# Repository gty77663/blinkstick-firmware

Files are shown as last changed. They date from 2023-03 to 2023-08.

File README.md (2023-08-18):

# BlinkStick Firmware

BlinkStick is a DIY open source USB RGB LED Controller. Original idea is to create a little & handy RGB stick, and make its code and protocol opensource, so everybody can enjoy playing with RGB LEDs using the programming launguage or application of your choise. It's small, the biggest model is the size of a credit card and supports both popular types of RGB LEDs - generic 12V ones and addressable WS2812. 

You can find more details about it here:

http://www.blinkstick.com

This branch contains the firmware required for the BlinkStick(original one), based around ATtiny45/85 chip.

- [BlinkStick Firmware](#blinkstick-firmware)
  - [BlinkStick types](#blinkstick-types)
  - [Serial number](#serial-number)
  - [BlinkStick communication protocol](#blinkstick-communication-protocol)
  - [EEPROM memory map](#eeprom-memory-map)
  - [How to build the firmware](#how-to-build-the-firmware)
    - [Windows](#windows)
    - [Linux](#linux)
    - [Mac-OS](#mac-os)
    - [Compiling](#compiling)
  - [TODO](#todo)
  - [License](#license)

## BlinkStick types
| Name | Description | Link |
|---|---|---|
| BlinkStick | Small formfactor of a USB stick with one WS2812 LED onboard, comes as a DIY kit. | [here](https://www.blinkstick.com/products/blinkstick) |
| BlinkStick Pro | USB stick-sized controller board for generic RGB and WS2812 LED strips. | [here](https://www.blinkstick.com/products/blinkstick-pro) |
| BlinkStick Square | Little handy square with 8 WS2812 LEDs and a micro-USB port. | [here](https://www.blinkstick.com/products/blinkstick-square) |
| BlinkStick Strip(mini) | Eight(4 for the mini version) WS2812LEDs shaped in one line & a micro-USB port. | [here](https://www.blinkstick.com/products/blinkstick-strip)  |
| BlinkStick Nano | Just like normal BlinkStick, but smaller, comes preassembled and has two WS2812 LEDs instead of one. | [here](https://www.blinkstick.com/products/blinkstick-nano) |
| BlinkStick Flex | Really small formfactor with a micro-USB port that supports up to 32 WS2812 LEDs in a strip. | [here](https://www.blinkstick.com/products/blinkstick-flex) |
| BlinkStick L3 | Combines BlinkStick Pro and LED Adapter to control normal, 12V RGB strips. | [here](https://www.blinkstick.com/products/blinkstick-l3) |
| BlinkStick Advanced | Combines both generic RGB and WS2812 controllers in a very small formfactor to act as a universal LED strips tool. | none for now |

## Serial number
Each BlinkStick has a unique serial number 12-byte long serial number, that consist of "BS" header, that stands for "BlinksStick",
followed by its index number, 6 symbols length. The footer is 4 bytes long, that signify the BlinkStick version it is.  
Ex: BS123456-1.0  
```
BSnnnnnn-1.0
||  |    | |- Software minor version
||  |    |--- Software major version
||  |-------- Denotes sequential number
||----------- Denotes BlinkStick device
```
Possible BlinkStick version are:  
* 1.x - BlinkStick
* 2.x - BlinkStick Pro
* 3.x - BlinkStick Square/Strip/Nano/Flex   
This are differentiate by the device version, aka firmware version.  

| Version | Description | N. of LEDs |
|---|---|---|
| 0x200 | BlinkStick Square | 8 |
| 0x201 | BlinkStick Strip  | 8 |
| 0x202 | BlinkStick Nano | 2 |
| 0x203 | BlinkStick Flex | ≤32 |
* 4.x - BlinkStick Advanced

## BlinkStick communication protocol

BlinkStick is controller via HID USB reports, each report has its unique id and is responsible for its specific purpose:  

| Report ID | Description | Format |
|---|---|---|
| 1 | Set\get RGB strip color or first ARGB LED color on first channel | [R, G, B] |
| 2 | Set\read the name of the BlinkStick | [Binary Data 0..32] |
| 3 | Set\read custom data stored in BlinkStick's EEPROM | [Binary Data 0..32] |
| 4 | Set\read current mode: 0 - RGB LED Strip, 1 - Inverse RGB LED Strip, 2 - WS2812, 3 - Advanced (WS2812 and RGB) | [MODE] |
| 5 | Set\read the value of one single ARGB LED on specified channel with INDEX | [CHANNEL, INDEX, R, G, B] |
| 6 | Set\read LED  from 0 to x (x≤7), on specified channel | [Channel, [G, R, B][0..7]]  |
| 7 | Set\read LED colors from 0 to x (x≤15), on specified channel | [Channel, [G, R, B][0..15]] |
| 8 | Set\read LED colors from 0 to x (x≤31), on specified channel | [Channel, [G, R, B][0..31]] |
| 9 | Set\read LED colors from 0 to x (x≤63), on specified channel | [Channel, [G, R, B][0..63]] |

## EEPROM memory map 
BlinkStick uses EEPROM to store some of power sensitive data, such as its Name, Serial, etc. 
  
| Address | Use |
|---|---|
| 0x00 | *unused* |
| 0x01-0x0C  | **Serial** |
| 0x0D | **Mode** |
| 0x0F-0x1F  | *unused* |
| 0x20-0x3F  | **Name** |
| 0x40-0x5F  | **Data** |
| 0x60-0x1FF | *unused* |

## How to build the firmware

### Windows   
* You'll need to install and add to system path [AVR-GCC toolchain](https://www.microchip.com/en-us/tools-resources/develop/microchip-studio/gcc-compilers)
* [Python3](https://www.python.org/downloads/)
* And [Make](https://www.gnu.org/software/make/#download) on you system. 

### Linux  
#### AVR-GCC toolchain  
    sudo apt-get update  
    sudo apt-get upgrade all
    sudo apt-get install gcc-avr binutils-avr avr-libc  

#### Python  
    sudo apt install python3 python3-pip
#### Make    
    sudo apt install make

### Mac-OS
#### AVR-GCC toolchain
First, you need to install HomeBrew:  

    ruby -e "$(curl -fsSL https://raw.githubusercontent.com/Homebrew/install/master/install)"

Then you can install avr toolchain, by typing two following commands:
First tap the repository:

    brew tap osx-cross/avr`

Then install the latest version of avr-libc (version 4.9.2 at the time of writing):

    brew install avr-libc

#### Python
You can download it from [python official site](https://www.python.org/downloads/macos/).

#### Make 
If you allready installed brew, paste this command in the terminal:

    brew install make

### Compiling
After installing all nessecery software, you can run make in project folder and choose one of the options that you need:
```
"This Makefile has no default rule. Use one of the following:"
"make hex ....... to build main.hex"
"make program ... to flash fuses and firmware"
"make fuse ...... to flash the fuses"
"make flash ..... to flash the firmware (use this on metaboard)"
"make dump ...... dump eeprom"
"make dumpflash . dump flash"
"make defaults .. write default eeprom"
"make clean ..... to delete objects and hex file"
"make deploy .... program, increment serial, defaults"
```

## TODO  
* Add BlinkStick devices support to SignalRGB
* Add BlinkStick devices support to OpenRGB
* Optional, maybe add built-in effects and animations, 

## License

Released under CC-BY-NC-SA 3.0 license:

http://creativecommons.org/licenses/by-nc-sa/3.0/

(c) 2013 by Agile Innovative Ltd  
(c) 2023 by gty77663

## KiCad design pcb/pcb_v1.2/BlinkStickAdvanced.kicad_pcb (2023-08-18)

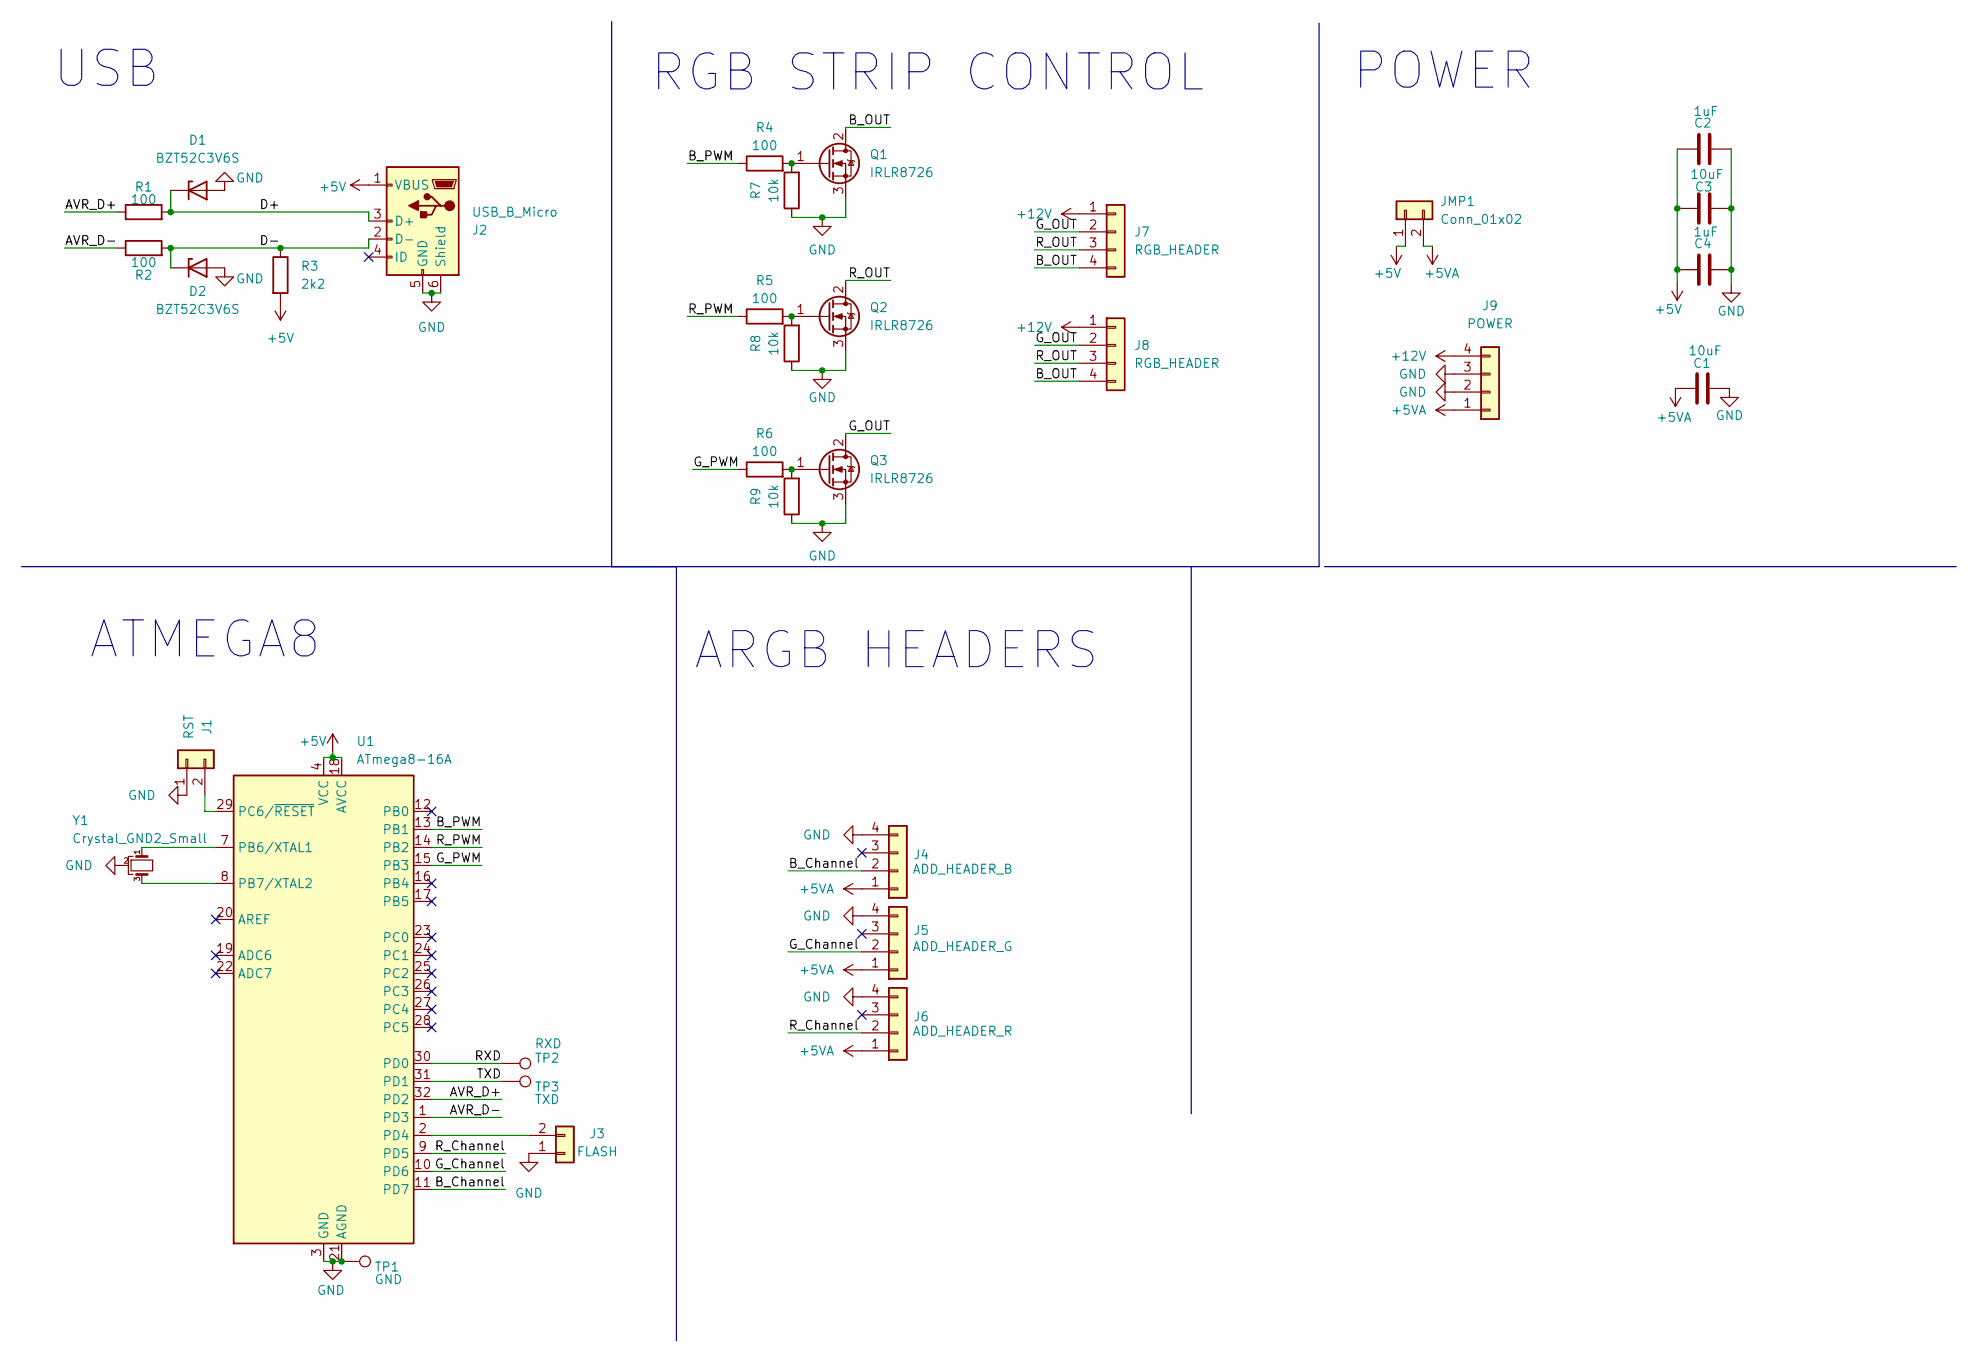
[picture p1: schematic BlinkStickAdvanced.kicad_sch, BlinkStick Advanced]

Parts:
C1, C3: 10uF; C_0603_1608Metric_Pad1.08x0.95mm_HandSolder
C2, C4: 1uF; C_0603_1608Metric_Pad1.08x0.95mm_HandSolder
D1, D2: BZT52C3V6S; D_SOD-323
J1: RST; PinHeader_1x02_P2.54mm_Vertical
J2: USB_B_Micro; USB_Micro-B_Molex-105017-0001
J3: FLASH; PinHeader_1x02_P2.54mm_Vertical
J4: ADD_HEADER_B; PinHeader_1x04_P2.54mm_Vertical
J5: ADD_HEADER_G; PinHeader_1x04_P2.54mm_Vertical
J6: ADD_HEADER_R; PinHeader_1x04_P2.54mm_Vertical
J7, J8: RGB_HEADER; PinHeader_1x04_P2.54mm_Vertical
J9: POWER; JST_XH_B4B-XH-A_1x04_P2.50mm_Vertical
JMP1: Conn_01x02; PinHeader_1x02_P2.54mm_Vertical
Q1, Q2, Q3: IRLR8726; TO-263-2
R1, R2, R4, R5, R6: 100; R_0603_1608Metric_Pad0.98x0.95mm_HandSolder
R3: 2k2; R_0603_1608Metric_Pad0.98x0.95mm_HandSolder
R7, R8, R9: 10k; R_0603_1608Metric_Pad0.98x0.95mm_HandSolder
TP1: GND; TestPoint_Pad_D1.5mm
TP2: RXD; TestPoint_Pad_D1.5mm
TP3: TXD; TestPoint_Pad_D1.5mm
U1: ATmega8-16A; TQFP-32_7x7mm_P0.8mm
Y1: Crystal_GND2_Small; Resonator_SMD_Murata_CSTxExxV-3Pin_3.0x1.1mm

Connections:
+5V: C2.2, C3.2, C4.2, J2.1 (VBUS), JMP1.1, R3.2, U1.4 (VCC), U1.6 (VCC), U1.18 (AVCC)
+5VA: C1.2, J4.1, J5.1, J6.1, J9.1, JMP1.2
+12V: J7.1, J8.1, J9.4
/AVR_D+: R1.1, U1.32 (PD2)
/AVR_D-: R2.1, U1.1 (PD3)
/B_Channel: J4.2, U1.11 (PD7)
/B_OUT: J7.4, J8.4, Q1.2 (D)
/B_PWM: R4.1, U1.13 (PB1)
/D+: D1.1 (K), J2.3 (D+), R1.2
/D-: D2.1 (K), J2.2 (D-), R2.2, R3.1
/G_Channel: J5.2, U1.10 (PD6)
/G_OUT: J7.2, J8.2, Q3.2 (D)
/G_PWM: R6.1, U1.15 (PB3)
/RXD: TP2.1, U1.30 (PD0)
/R_Channel: J6.2, U1.9 (PD5)
/R_OUT: J7.3, J8.3, Q2.2 (D)
/R_PWM: R5.1, U1.14 (PB2)
/TXD: TP3.1, U1.31 (PD1)
GND: C1.1, C2.1, C3.1, C4.1, D1.2 (A), D2.2 (A), J1.1, J2.5 (GND), J2.6 (Shield), J3.1, J4.4, J5.4, J6.4, J9.2, J9.3, Q1.3 (S), Q2.3 (S), Q3.3 (S), R7.1, R8.1, R9.1, TP1.1, U1.3 (GND), U1.5 (GND), U1.21 (AGND), Y1.2
unnamed: Q1.1 (G), R4.2, R7.2
unnamed: Q2.1 (G), R5.2, R8.2
unnamed: Q3.1 (G), R6.2, R9.2
unnamed: J3.2, U1.2 (PD4)
unnamed: U1.7 (PB6/XTAL1), Y1.1
unnamed: U1.8 (PB7/XTAL2), Y1.3
unnamed: J1.2, U1.29 (PC6/~RESET)

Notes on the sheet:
RGB STRIP CONTROL
POWER
ATMEGA8
USB
ARGB HEADERS

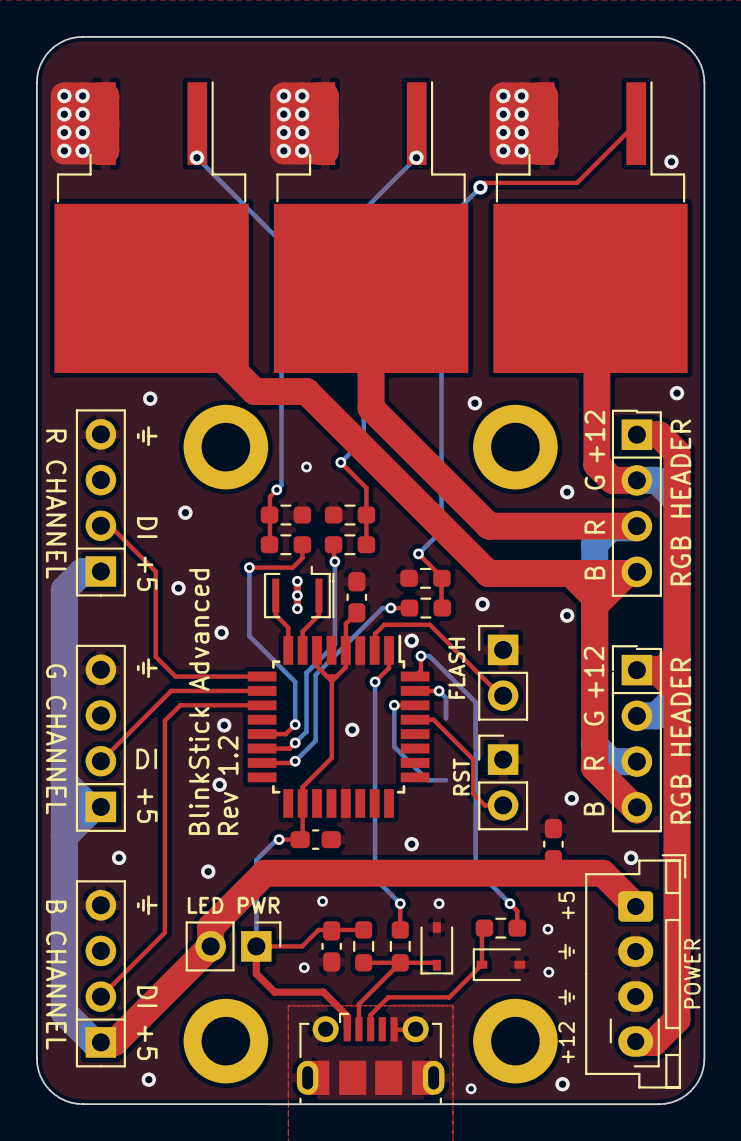
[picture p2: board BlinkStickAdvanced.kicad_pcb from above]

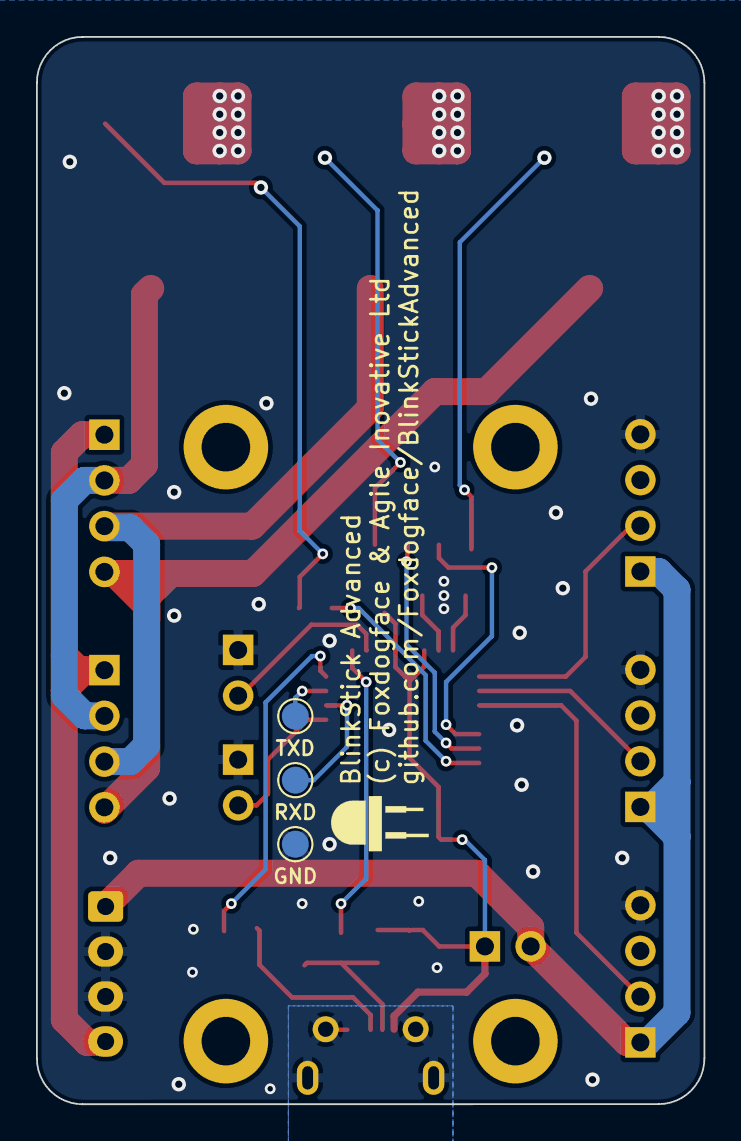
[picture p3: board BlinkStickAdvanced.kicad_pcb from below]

Board: 2 copper layers, 37.1 x 59.3 mm, 33 parts (3 on the bottom side), 26 nets.

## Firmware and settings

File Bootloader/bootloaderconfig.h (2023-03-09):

/* Name: bootloaderconfig.h
 * Project: USBaspLoader
 * Author: Christian Starkjohann
 * Creation Date: 2007-12-08
 * Tabsize: 4
 * Copyright: (c) 2007 by OBJECTIVE DEVELOPMENT Software GmbH
 * License: GNU GPL v2 (see License.txt)
 * This Revision: $Id$
 */

#ifndef __bootloaderconfig_h_included__
#define __bootloaderconfig_h_included__

/*
General Description:
This file (together with some settings in Makefile) configures the boot loader
according to the hardware.

This file contains (besides the hardware configuration normally found in
usbconfig.h) two functions or macros: bootLoaderInit() and
bootLoaderCondition(). Whether you implement them as macros or as static
inline functions is up to you, decide based on code size and convenience.

bootLoaderInit() is called as one of the first actions after reset. It should
be a minimum initialization of the hardware so that the boot loader condition
can be read. This will usually consist of activating a pull-up resistor for an
external jumper which selects boot loader mode.

bootLoaderCondition() is called immediately after initialization and in each
main loop iteration. If it returns TRUE, the boot loader will be active. If it
returns FALSE, the boot loader jumps to address 0 (the loaded application)
immediately.

For compatibility with Thomas Fischl's avrusbboot, we also support the macro
names BOOTLOADER_INIT and BOOTLOADER_CONDITION for this functionality. If
these macros are defined, the boot loader usees them.
*/

/* ---------------------------- Hardware Config ---------------------------- */

#define USB_CFG_IOPORTNAME      D
/* This is the port where the USB bus is connected. When you configure it to
 * "B", the registers PORTB, PINB and DDRB will be used.
 */
#define USB_CFG_DMINUS_BIT      3
/* This is the bit number in USB_CFG_IOPORT where the USB D- line is connected.
 * This may be any bit in the port.
 */
#define USB_CFG_DPLUS_BIT       2
/* This is the bit number in USB_CFG_IOPORT where the USB D+ line is connected.
 * This may be any bit in the port. Please note that D+ must also be connected
 * to interrupt pin INT0!
 */
#define USB_CFG_CLOCK_KHZ       (F_CPU/1000)
/* Clock rate of the AVR in MHz. Legal values are 12000, 16000 or 16500.
 * The 16.5 MHz version of the code requires no crystal, it tolerates +/- 1%
 * deviation from the nominal frequency. All other rates require a precision
 * of 2000 ppm and thus a crystal!
 * Default if not specified: 12 MHz
 */

/* ----------------------- Optional Hardware Config ------------------------ */

/* #define USB_CFG_PULLUP_IOPORTNAME   D */
/* If you connect the 1.5k pullup resistor from D- to a port pin instead of
 * V+, you can connect and disconnect the device from firmware by calling
 * the macros usbDeviceConnect() and usbDeviceDisconnect() (see usbdrv.h).
 * This constant defines the port on which the pullup resistor is connected.
 */
/* #define USB_CFG_PULLUP_BIT          4 */
/* This constant defines the bit number in USB_CFG_PULLUP_IOPORT (defined
 * above) where the 1.5k pullup resistor is connected. See description
 * above for details.
 */

/* ------------------------------------------------------------------------- */
/* ---------------------- feature / code size options ---------------------- */
/* ------------------------------------------------------------------------- */

#define HAVE_EEPROM_PAGED_ACCESS    1
/* If HAVE_EEPROM_PAGED_ACCESS is defined to 1, page mode access to EEPROM is
 * compiled in. Whether page mode or byte mode access is used by AVRDUDE
 * depends on the target device. Page mode is only used if the device supports
 * it, e.g. for the ATMega88, 168 etc. You can save quite a bit of memory by
 * disabling page mode EEPROM access. Costs ~ 138 bytes.
 */
#define HAVE_EEPROM_BYTE_ACCESS     1
/* If HAVE_EEPROM_BYTE_ACCESS is defined to 1, byte mode access to EEPROM is
 * compiled in. Byte mode is only used if the device (as identified by its
 * signature) does not support page mode for EEPROM. It is required for
 * accessing the EEPROM on the ATMega8. Costs ~54 bytes.
 */
#define BOOTLOADER_CAN_EXIT         1
/* If this macro is defined to 1, the boot loader will exit shortly after the
 * programmer closes the connection to the device. Costs ~36 bytes.
 */
#define HAVE_CHIP_ERASE             0
/* If this macro is defined to 1, the boot loader implements the Chip Erase
 * ISP command. Otherwise pages are erased on demand before they are written.
 */
//#define SIGNATURE_BYTES             0x1e, 0x93, 0x07, 0     /* ATMega8 */
/* This macro defines the signature bytes returned by the emulated USBasp to
 * the programmer software. They should match the actual device at least in
 * memory size and features. If you don't define this, values for ATMega8,
 * ATMega88, ATMega168 and ATMega328 are guessed correctly.
 */
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

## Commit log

2023-01-23 PCB Change Silkscreen
    [BlinkStickAdvanced.kicad_pcb]
2023-03-09 USBaspLoader support for PCB.
    [BlinkStickAdvanced.kicad_pcb, BlinkStickAdvanced.kicad_sch]
2023-08-18 Add new PCB version with right-angled connectors instead of straight ones.
    [BlinkStickAdvanced-B_Cu.gbl, BlinkStickAdvanced-B_Mask.gbs, BlinkStickAdvanced-B_Paste.gbp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]
2023-08-18 Move old PCB files to a different folder.
    [BlinkStickAdvanced-B_Cu.gbl, BlinkStickAdvanced-B_Mask.gbs, BlinkStickAdvanced-B_Paste.gbp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]
